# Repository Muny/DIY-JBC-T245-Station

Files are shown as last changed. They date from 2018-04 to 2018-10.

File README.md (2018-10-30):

This is a project I've been working on for a little bit. Any questions are very welcome!

It's an "equivalent performance" JBC T245 soldering iron stand.

## Videos in-action
[V2](https://www.youtube.com/watch?v=oT_kzjgQcro)

[V1](https://www.youtube.com/watch?v=Gup-r7FQM7E)

## Schematics & PCB Layout
https://easyeda.com/Muny/JBC-T245-Iron-Controller

## Pictures
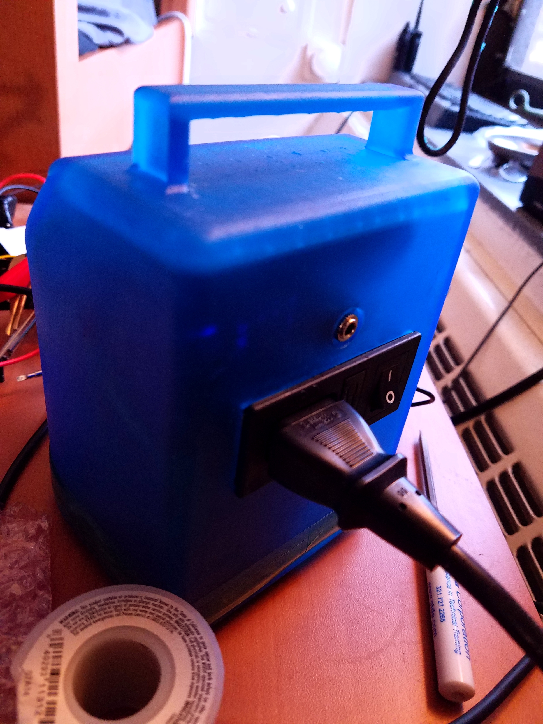
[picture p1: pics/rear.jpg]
Rear
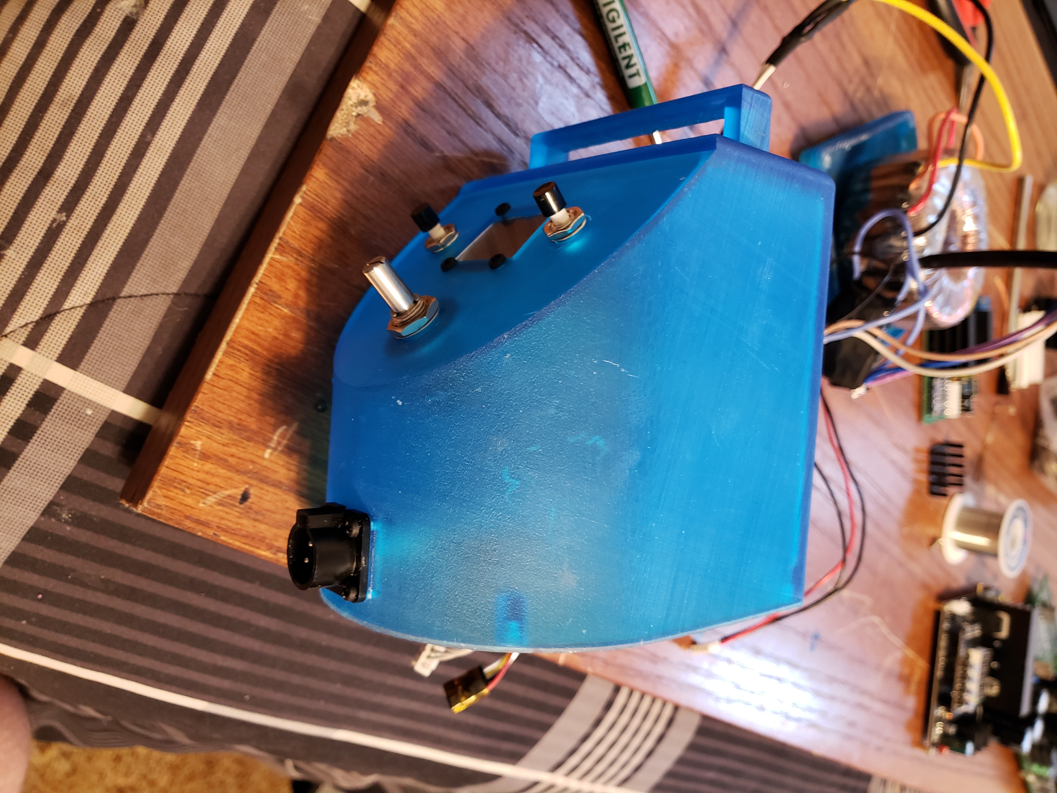
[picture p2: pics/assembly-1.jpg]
Assembly 1
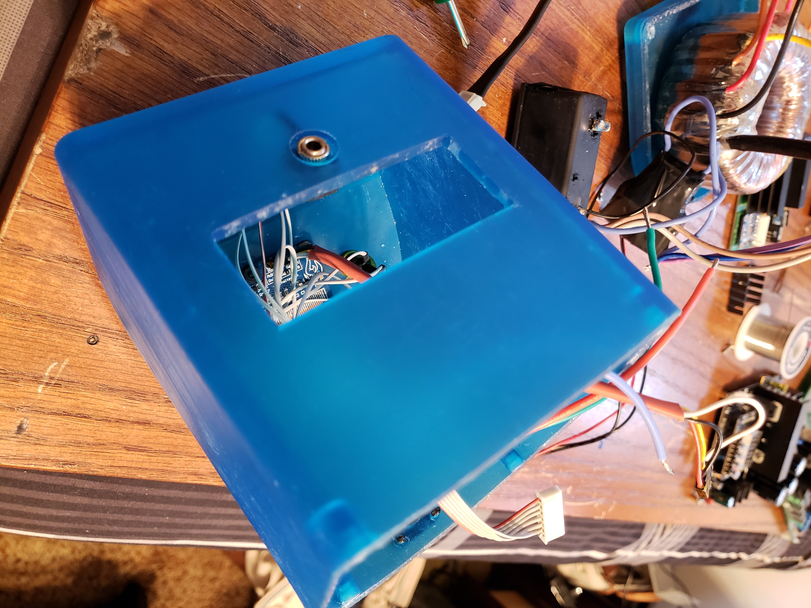
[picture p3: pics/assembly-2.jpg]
Assembly 2
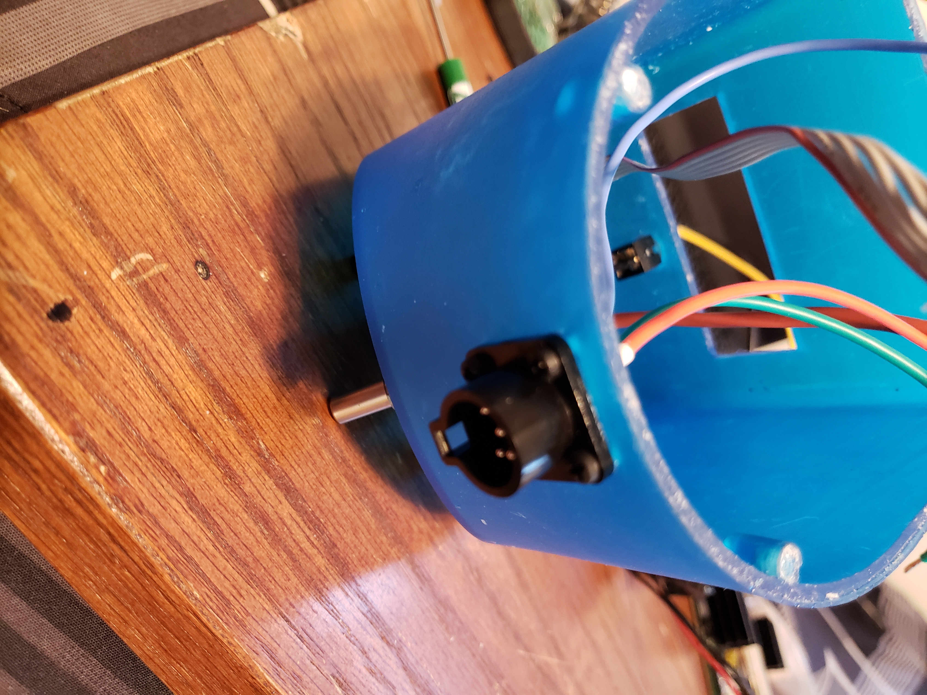
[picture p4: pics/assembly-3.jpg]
Assembly 3
Front Profile    

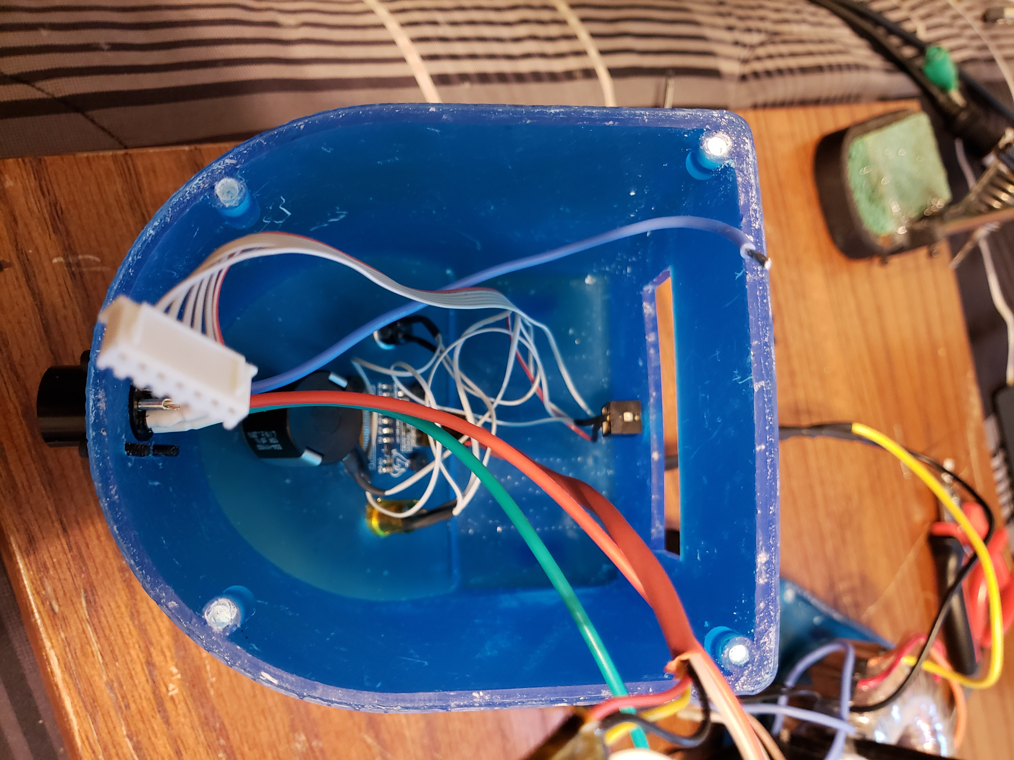
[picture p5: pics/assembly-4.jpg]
Assembly 4
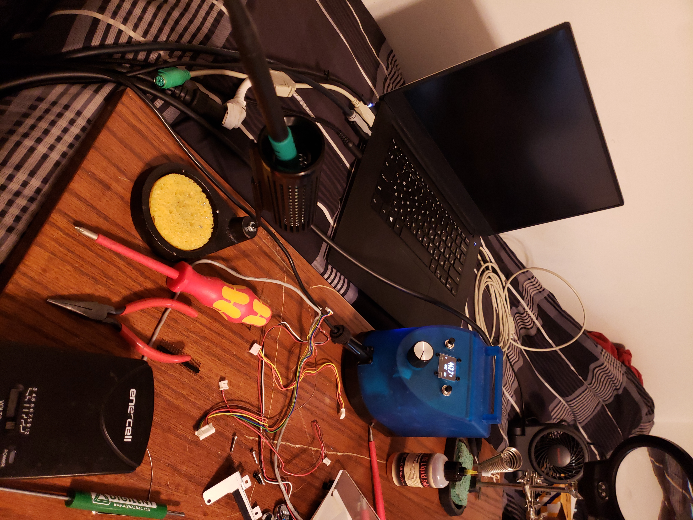
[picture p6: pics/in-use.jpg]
In Use
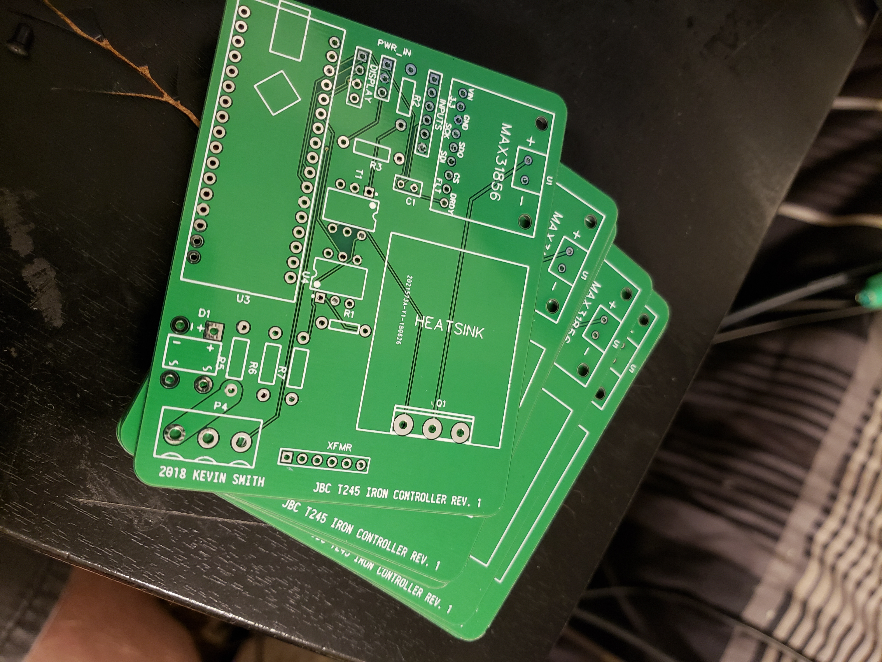
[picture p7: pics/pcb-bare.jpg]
PCB Bare
 Assembly 5  
PCB Assembled

## About the Design

The case was designed in OpenJSCAD and printed on a FormLabs Form 2.

It uses:
* A 100VA 120v to 2x12V toroidal transformer (with the two 12v outputs in series for 24v)
* A simple isolated triac driver circuit
* A simple isolated zero crossing detector circuit
* A MAX31856 thermocouple amplifier.
     * I expected the thermocouple to be of a common type, but it wasn't. So I'm only using this chip in voltage gain mode, and then plugging in the value to an equation I got by linear-fitting a couple voltage-heat data points when sticking the iron tip into liquids of varying temperature and using the melting points of leaded and lead-free solder. I'm not very worried about accuracy, but it seems to be within 10F. The output isn't linear towards the lower end though, hence the ~120F when it's actually about 80F.
* An Arduino Micro. 
    * The code was the most interesting part. A PID control loop was implemented using the Arduino PID library (very handy!). There is quite a bit of overshoot though, meaning I still need to tune the parameters. 

It responds to heat changes extremely responsively though, as seen in the penny test at the end of the video. 

There is a jack on the back for connection to a micro-switch on a stand to put the iron into sleep mode.

Another interesting part was the final sketch size. The fonts used take up a massive portion of the available space.

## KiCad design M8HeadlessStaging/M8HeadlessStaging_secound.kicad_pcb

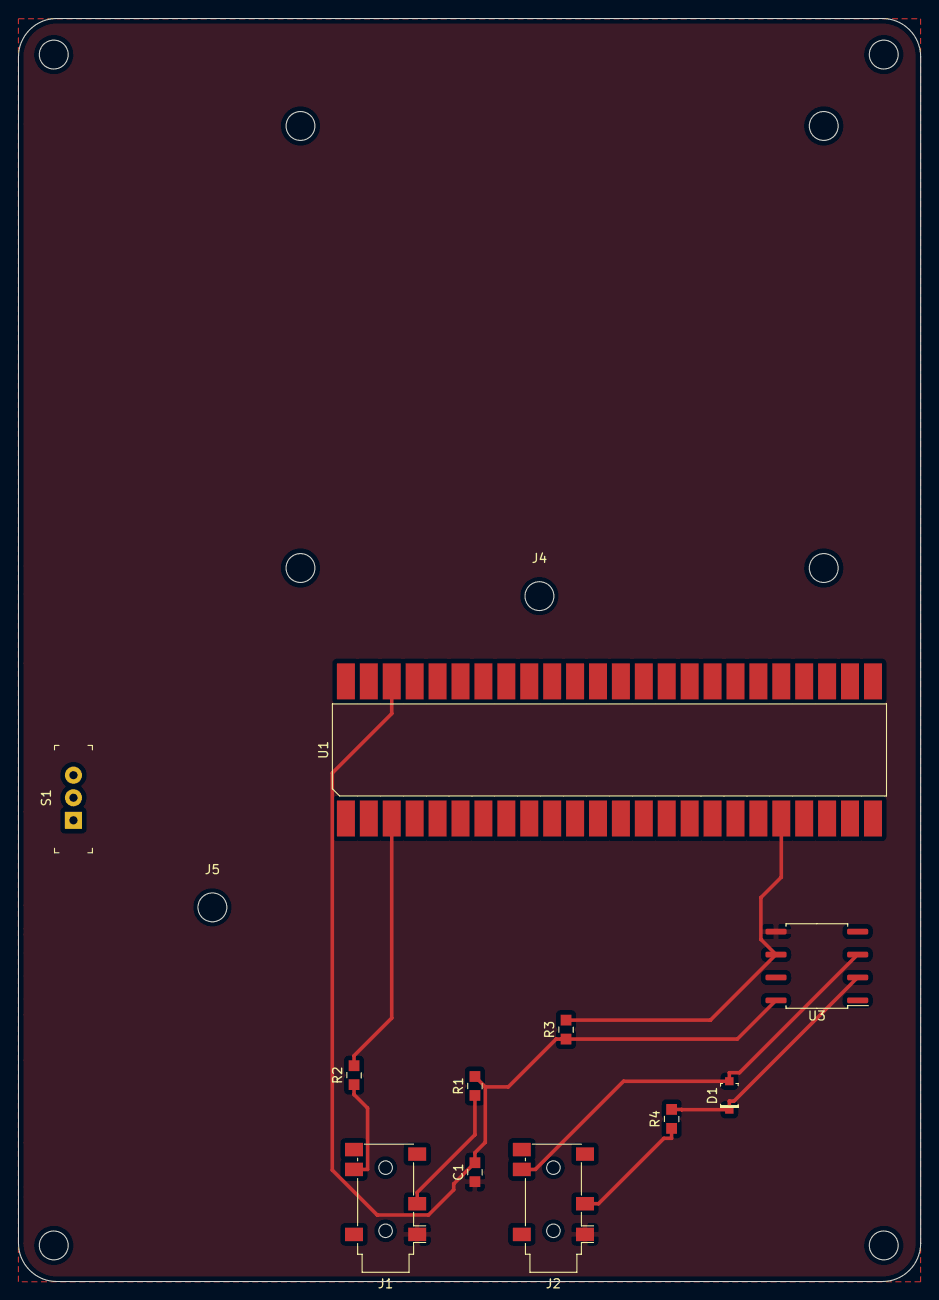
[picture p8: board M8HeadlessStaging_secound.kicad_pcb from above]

Board: 2 copper layers, 100.0 x 140.0 mm, 13 parts (0 on the bottom side), 11 nets.

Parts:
C1: 0.1uF; 0805
D1: 1n4148; SOD-123
J1: MIDI OUT; Jack_3.5mm_PJ311_Horizontal
J2: MIDI IN; Jack_3.5mm_PJ311_Horizontal
J4: TO_RASP_VIN; MountingHole_3.2mm_M3
J5: TO_BAT_MODULE; MountingHole_3.2mm_M3
R1, R2: 47R; 0805
R3: 470R; 0805
R4: 220R; 0805
S1: SLIDE_SWITCH; Switch_Slide_11.6x4mm_EG1218
U1: Teensy4.1; TEENSY4.1
U3: 6N138; SOP-8_6.62x9.15mm_P2.54mm

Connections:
+3V3: C1.2, R1.2, R3.1, U1.46, U3.8
GND: C1.1, J1.1, J2.1, U3.5
unnamed: D1.K, R4.2, U3.2
unnamed: D1.A, J2.4, U3.3
unnamed: J1.3, R1.1
unnamed: J1.4, R2.1
unnamed: J2.3, R4.1
unnamed: J4.1, S1.2
unnamed: J5.1, S1.1
RX1: R3.2, U1.20, U3.6
TX1: R2.2, U1.3

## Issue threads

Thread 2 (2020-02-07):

Sketch size is 117%

mmanchev, 2020-02-07:
Hi, I've tried to compile the code for ARDUINO Micro and get this error message -
`arduino_build_435270/arduino_t245_controller.ino.elf
Sketch uses 33730 bytes (117%) of program storage space. Maximum is 28672 bytes.

Global variables use 660 bytes (25%) of dynamic memory, leaving 1900 bytes for local variables. Maximum is 2560 bytes.
Sketch too big; see http://www.arduino.cc/en/Guide/Troubleshooting#size for tips on reducing it.
Error compiling for board Arduino Micro.`

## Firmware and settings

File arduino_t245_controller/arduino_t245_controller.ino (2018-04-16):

#include <Arduino.h>
#include <MAX31856.h>
#include <PID_v1.h>
#include <Bounce2.h>

#include <Adafruit_GFX.h>
#include <Adafruit_SSD1306.h>

#define FONT_BIG futura_medium_condensed_bt22pt7b
#define FONT_SMALL futura_medium_condensed_bt9pt7b
#include "futuramdcn22pt7b.h"
#include "futuramdcn9pt7b.h"

Adafruit_SSD1306 display;

#define GATE_PIN 12         // PD6
#define ZERO_CROSSING_PIN 7 // PE6
#define DRDY_PIN 10         // PB6
#define SLEEP_PIN 11        // PB7

#define LEFT_BUTTON_PIN 8  // PB4
#define RIGHT_BUTTON_PIN 9 // PB5

volatile unsigned long lastInterrupt = 0;

// Pins for the display
#define SCK SCK
#define CS 4
#define SDI MOSI
#define SDO MISO

// MAX31856 Initial settings (see MAX31856.h and the MAX31856 datasheet)
// The default noise filter is 60Hz, suitable for the USA
#define CR0_INIT (CR0_AUTOMATIC_CONVERSION + CR0_OPEN_CIRCUIT_FAULT_TYPE_K /* + CR0_NOISE_FILTER_50HZ */)
#define CR1_INIT (CR1_AVERAGE_1_SAMPLE + CR1_VOLTAGE_MODE_GAIN_32)
#define MASK_INIT (~(MASK_VOLTAGE_UNDER_OVER_FAULT + MASK_THERMOCOUPLE_OPEN_FAULT))

MAX31856 *temperature;

double currTemp = 0;

unsigned long lastSample = 0;
double wait = 7800;

double targetTemp = 0;

double userTemp = 0;

bool SLEEP = false;
bool OVERRIDE_DISABLE_HEATER = false;
bool USER_DISABLE_HEATER = false;

char displayCurrTempStr[5] = "000.0";
char displaySetTempStr[5] = "000.0";
char displayWaitStr[4] = "0000";
char displaySleepStr[1] = "0";

volatile unsigned long scheduledPulse = 0;
volatile bool doPulse = false;

double Kp = 35, Ki = 26, Kd = 35;

//double Kp = 30, Ki = 16, Kd = 17.5;
PID myPID(&currTemp, &wait, &targetTemp, Kp, Ki, Kd, REVERSE);

Bounce leftDebouncer = Bounce();
Bounce rightDebouncer = Bounce();

#define MAIN_PAGE 0
#define SET_TEMP_PAGE 1

uint8_t CURRENT_PAGE = MAIN_PAGE;

unsigned long lastDisplayUpdate = 0;

void setup()
{
    delay(300);

    /*pinMode(13, OUTPUT);
    digitalWrite(13, HIGH);
    delay(100);
    digitalWrite(13, LOW);
    delay(100);
    digitalWrite(13, HIGH);
    delay(100);
    digitalWrite(13, LOW);*/

    myPID.SetOutputLimits(800, 7800);
    myPID.SetSampleTime(100);

    myPID.SetMode(AUTOMATIC);

    //pinMode(DRDY_PIN, INPUT_PULLUP);
    // make drdy pin input and pulled-up
    DDRB = DDRB & B10111111;
    PORTB = PORTB | B01000000;

    //pinMode(SLEEP_PIN, INPUT_PULLUP);
    // make sleep pin input and pulled-up
    DDRB = DDRB & B01111111;
    PORTB = PORTB | B10000000;

    //pinMode(ZERO_CROSSING_PIN, INPUT_PULLUP);
    // make zero crossing pin input and pulled-up
    DDRE = DDRE & B10111111;
    PORTE = PORTE | B01000000;

    //pinMode(GATE_PIN, OUTPUT);
    // make gate pin output
    DDRD = DDRD | B01000000;

    pinMode(LEFT_BUTTON_PIN, INPUT_PULLUP);
    // setup left button  pb4
    //DDRB = DDRB & B11101111;
    //PORTB = DDRB | B00010000;
    leftDebouncer.attach(LEFT_BUTTON_PIN);
    leftDebouncer.interval(5);

    pinMode(RIGHT_BUTTON_PIN, INPUT_PULLUP);
    // setup right button pb5
    //DDRB = DDRB & B11011111;
    //PORTB = PORTB | B00100000;
    rightDebouncer.attach(RIGHT_BUTTON_PIN);
    rightDebouncer.interval(5);

    temperature = new MAX31856(SDI, SDO, CS, SCK);

    // Initializing the MAX31855's registers
    temperature->writeRegister(REGISTER_CR0, CR0_INIT);
    temperature->writeRegister(REGISTER_CR1, CR1_INIT);
    temperature->writeRegister(REGISTER_MASK, MASK_INIT);

    display.begin(SSD1306_SWITCHCAPVCC, 0x3C);
    display.clearDisplay();

    display.setTextWrap(false);
    display.setTextSize(1);
    display.setTextColor(WHITE);
    display.setCursor(0, 0);

    updateDisplay();

    attachInterrupt(digitalPinToInterrupt(ZERO_CROSSING_PIN), zeroCrossingInterrupt, RISING);
}

// 0 == not waiting for temp
// 1 == waiting for first bogus
// 2 == waiting for second bogus
// 3 == waiting for third bogus
// when got third bogus in state == 2, go to 0
uint8_t TEMP_GRAB_STATE = 0;

void loop()
{
    leftDebouncer.update();
    rightDebouncer.update();

    if (leftDebouncer.fell())
    {
        USER_DISABLE_HEATER = !USER_DISABLE_HEATER;
    }
    else if (rightDebouncer.fell())
    {
        switch (CURRENT_PAGE)
        {
            case MAIN_PAGE:
            {
                CURRENT_PAGE = SET_TEMP_PAGE;
                break;
            }
            case SET_TEMP_PAGE:
            {
                CURRENT_PAGE = MAIN_PAGE;

                targetTemp = userTemp;

                break;
            }
        }
    }

    bool didSampleTemp = false;

    if (TEMP_GRAB_STATE == 0)
    {
        if (doPulse && !SLEEP && !OVERRIDE_DISABLE_HEATER && !USER_DISABLE_HEATER)
        {
            if (micros() >= scheduledPulse)
            {
                doPulse = false;

                digitalWrite(GATE_PIN, HIGH);
                digitalWrite(GATE_PIN, LOW);

                /*PORTD = PORTD | B01000000;
                delayMicroseconds(2);
                PORTD = PORTD & B10111111;*/
            }
        }

        if (millis() - lastSample > 400)
        {
            //noInterrupts();

            TEMP_GRAB_STATE++;

            getRidOfBogusReading();
        }
    }
    else if (TEMP_GRAB_STATE < 4)
    {
        if (!(PINB & B01000000))
        {
            TEMP_GRAB_STATE++;
            getRidOfBogusReading();
        }
    }
    else
    {
        // we got third bogus...let's update for real

        currTemp = readTemp();

        // check if sleep pin is asserted

        SLEEP = !(PINB & B10000000);
        //SLEEP = !digitalRead(SLEEP_PIN);

        if (currTemp > 999.9)
        {
            if (SLEEP)
                currTemp = 0;
            else
            {
                OVERRIDE_DISABLE_HEATER = true;
                currTemp = 999.9;
            }
        }
        else if (currTemp < 0)
        {
            currTemp = 0;
        }
        else
        {
            OVERRIDE_DISABLE_HEATER = false;
        }

        myPID.SetSampleTime(millis() - lastSample);

        lastSample = millis();

        didSampleTemp = true;

        TEMP_GRAB_STATE = 0;

        if (CURRENT_PAGE == SET_TEMP_PAGE)
        {
            userTemp = getUserTemp();
        }

        // we can now re-enable interrupts
        //interrupts();
    }

    if (!SLEEP && !OVERRIDE_DISABLE_HEATER && !USER_DISABLE_HEATER && currTemp != 0)
        myPID.Compute();

    // update more quickly if we're accepting user input

    /*if (CURRENT_PAGE == SET_TEMP_PAGE && millis() - lastDisplayUpdate >= 20)
    {
        didSampleTemp = true;
        userTemp = getUserTemp();
    }*/

    if (didSampleTemp)
    {
        updateDisplay();
    }
}

void getRidOfBogusReading()
{
    readTemp();
    delayMicroseconds(100);
    /*while (PINB & B01000000)
    //while (digitalRead(DRDY_PIN))
    {
        ;
    }*/
}

void updateDisplay()
{
    display.clearDisplay();

    if (CURRENT_PAGE == MAIN_PAGE)
        drawMainPage();
    else if (CURRENT_PAGE == SET_TEMP_PAGE)
        drawSetTempPage();

    display.display();

    lastDisplayUpdate = millis();
}

void drawMainPage()
{
    display.setFont(&FONT_BIG);

    dtostrf(currTemp, 5, 1, displayCurrTempStr);

    display.setCursor(25, 36);
    display.print(displayCurrTempStr);

    display.setFont(&FONT_SMALL);

    display.setCursor(110, 24);
    display.print("F");

    dtostrf(targetTemp, 5, 1, displaySetTempStr);

    display.setCursor(48, 60);
    display.print(displaySetTempStr);

    display.setFont();

    dtostrf(wait, 4, 0, displayWaitStr);

    display.setCursor(102, 52);
    display.print(displayWaitStr);

    dtostrf(SLEEP, 1, 0, displaySleepStr);

    display.setCursor(1, 52);
    display.print(displaySleepStr);

    if (OVERRIDE_DISABLE_HEATER || USER_DISABLE_HEATER)
        display.invertDisplay(true);
    else
        display.invertDisplay(false);
}

void drawSetTempPage()
{
    display.setFont(&FONT_BIG);

    dtostrf(userTemp, 5, 1, displayCurrTempStr);

    display.setCursor(25, 36);
    display.print(displayCurrTempStr);

    display.setFont(&FONT_SMALL);

    display.setCursor(110, 24);
    display.print("F");

    display.setCursor(48, 60);
    display.print("SET");
}

void zeroCrossingInterrupt()
{
    if (!SLEEP)
    {
        if (millis() - lastInterrupt > 1)
        {
            lastInterrupt = millis();

            doPulse = true;

            scheduledPulse = micros() + wait;
        }
    }
}

double getUserTemp()
{
    return mapdouble(analogRead(A0), 0, 1023, 300, 700);
}

double readTemp()
{
    return 122.5438816 + 5.66934596 * temperature->readThermocoupleVoltage();
}

double mapdouble(double x, double in_min, double in_max, double out_min, double out_max)
{
    return (x - in_min) * (out_max - out_min) / (in_max - in_min) + out_min;
}

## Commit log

2018-07-03 added schematic & pcb link
2018-10-30 added v2 video to readme
    [Gerber_BoardOutline.GKO, Gerber_BottomLayer.GBL, Gerber_BottomSolderMaskLayer.GBS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]
